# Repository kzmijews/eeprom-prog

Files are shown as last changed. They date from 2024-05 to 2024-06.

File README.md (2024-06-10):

# EEPROM programer

## Overview
EEPROM programer dedicated for AT28C16 memory.
Electrical schema was created in [EAGLE](https://www.autodesk.com/products/eagle/overview):

<div>
    <p align="center" width="100%">
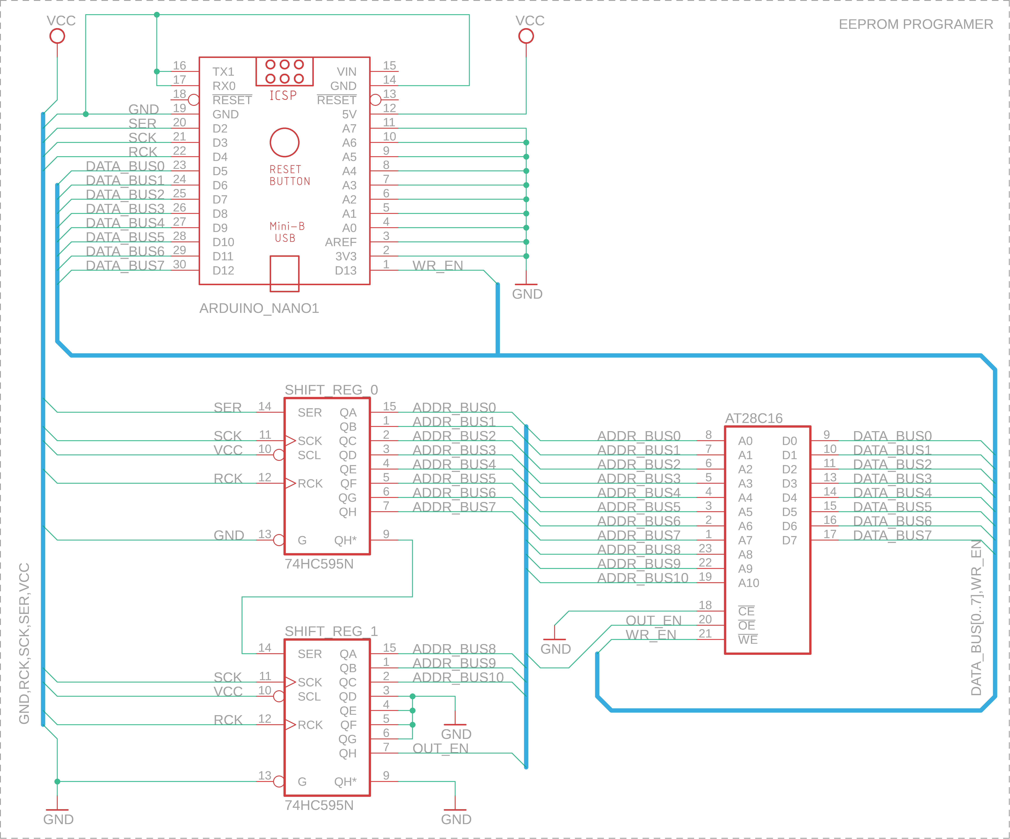
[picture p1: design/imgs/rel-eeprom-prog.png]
        
    </p>
    <p align="center">
        <i>Figure 1.1: EEPROM prog schema</i>
    </p>
</div>

Same as board design:

<div>
    <p align="center" width="100%">
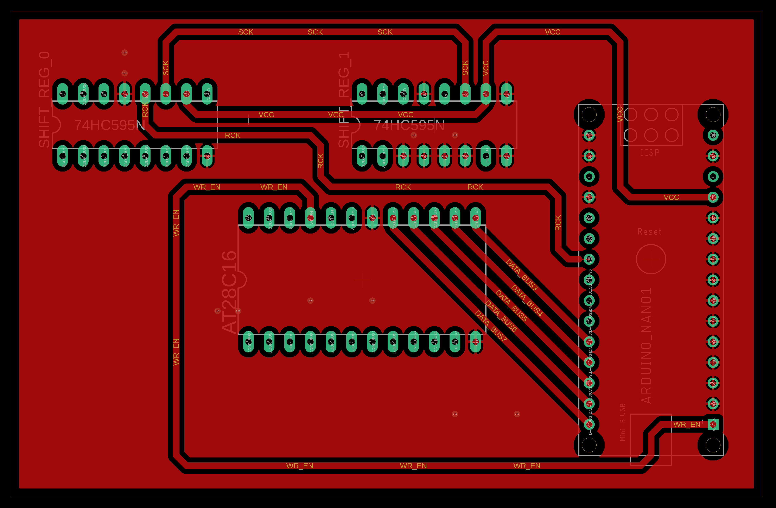
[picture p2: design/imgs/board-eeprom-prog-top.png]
        
    </p>
    <p align="center">
        <i>Figure 1.2: top layer of EEPROM prog board</i>
    </p>
</div>

<div>
    <p align="center" width="100%">
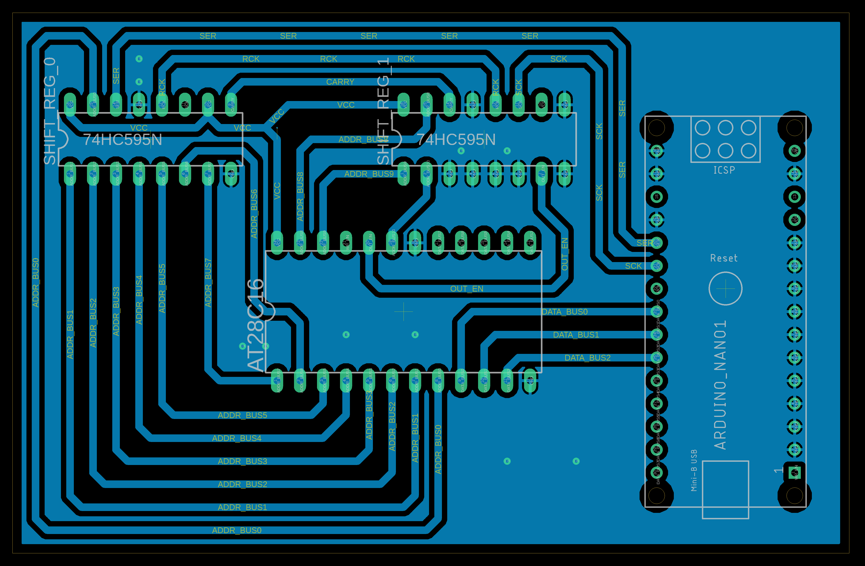
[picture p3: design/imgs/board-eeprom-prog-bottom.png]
        
    </p>
    <p align="center">
        <i>Figure 1.3: bottom layer of EEPROM prog board</i>
    </p>
</div>

It was done based on Arduino Nano 3.0 (ATmega328P):

<div>
    <p align="center" width="100%">
        
    </p>
    <p align="center">
        <i>Figure 1.4: Possible implementation on prototype board</i>
    </p>
</div>

Software library is written in C++, and it's available in `code/eeprom`.
To use it copy `eeprom` folder into your sketch directory (to check directory from [Arduino IDE](https://www.arduino.cc/en/software):
go into: File -> Preferences -> Settings -> Sketchbook location), and load it (Sketch -> Include Library -> eeprom). It will add
"include <eeprom.h>" header file to your project.

## Usage
Available API:
- **begin()**: configure pins and serial output
- **setAddress(unsigned int address, bool rw_bit)**: choose memory address to perform action over the pointed cell
- **read(unsigned int address)**: read byte of data from memory address
- **write(unsigned int address, byte data)**: write byte of data under memory address
- **print(byte data_row_size, unsigned int data_total_size)**: print on serial output (COM) piece of memory content
- **clean()**: write whole memory chip with value 0x00
- **erase()**: erase whole memory chip by writing 0xFF
- **writeAll(byte value)**: write whole memory chip with given value

Example:
```cpp
#include <eeprom.h>

EEPROM eeprom;

void setup() {
    // configure library
    eeprom.begin();
    // write byte (0x01) of data at address 0x00
    eeprom.write(0x00, 0x01);
    // print two rows of data (16 bytes per row, 32 bytes in total)
    eeprom.print(16, 32);
    // read single byte of data from address
    byte read_data = eeprom.read(0x00);
}

void loop() {
}
```

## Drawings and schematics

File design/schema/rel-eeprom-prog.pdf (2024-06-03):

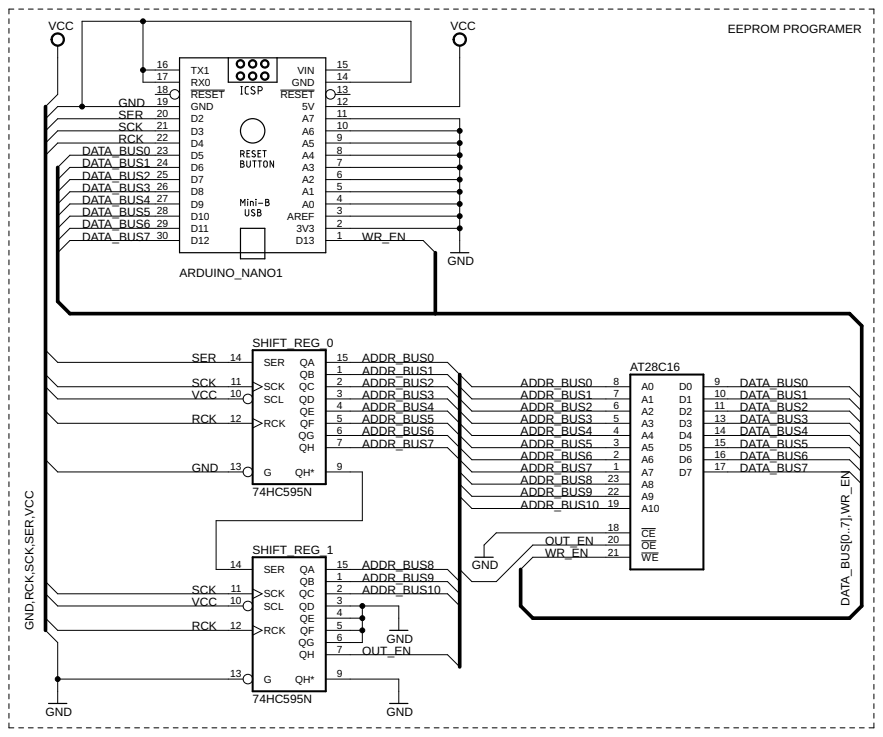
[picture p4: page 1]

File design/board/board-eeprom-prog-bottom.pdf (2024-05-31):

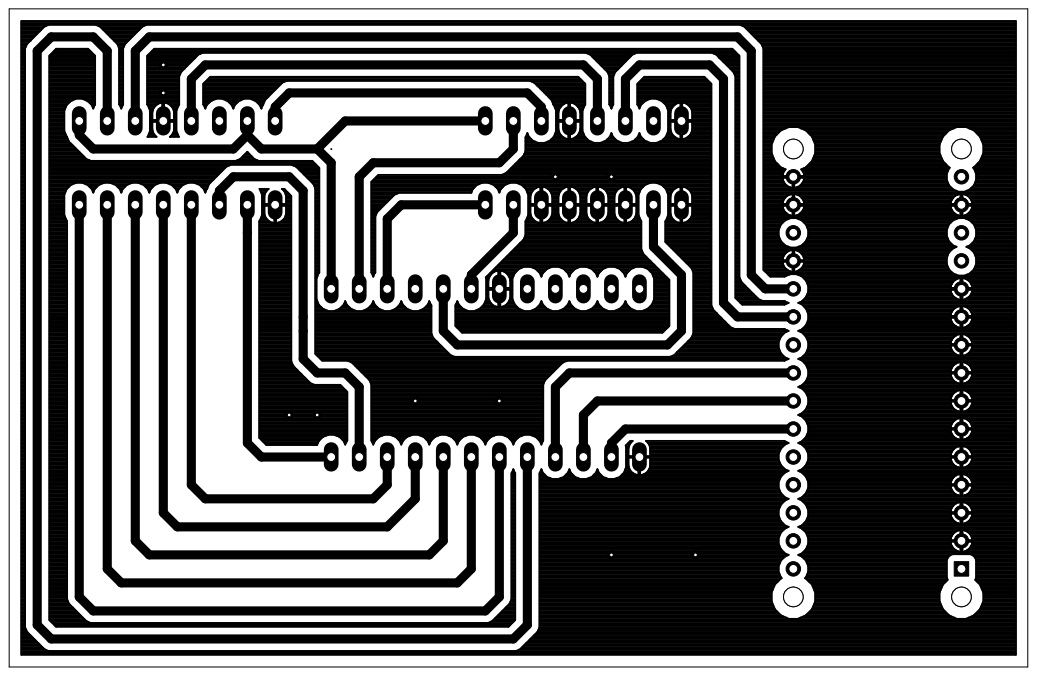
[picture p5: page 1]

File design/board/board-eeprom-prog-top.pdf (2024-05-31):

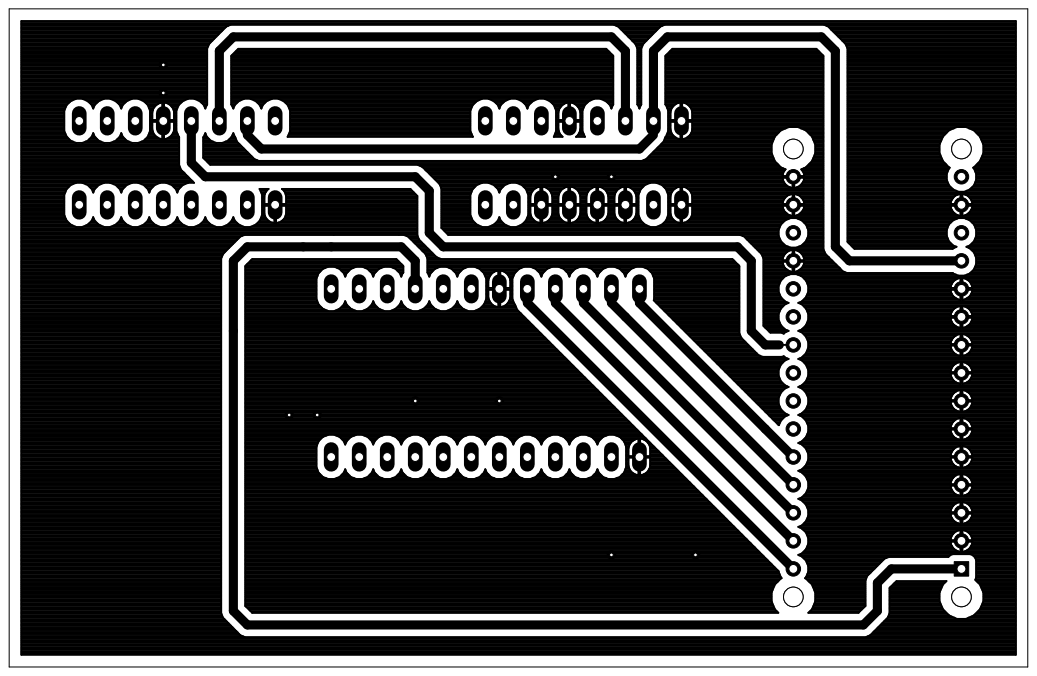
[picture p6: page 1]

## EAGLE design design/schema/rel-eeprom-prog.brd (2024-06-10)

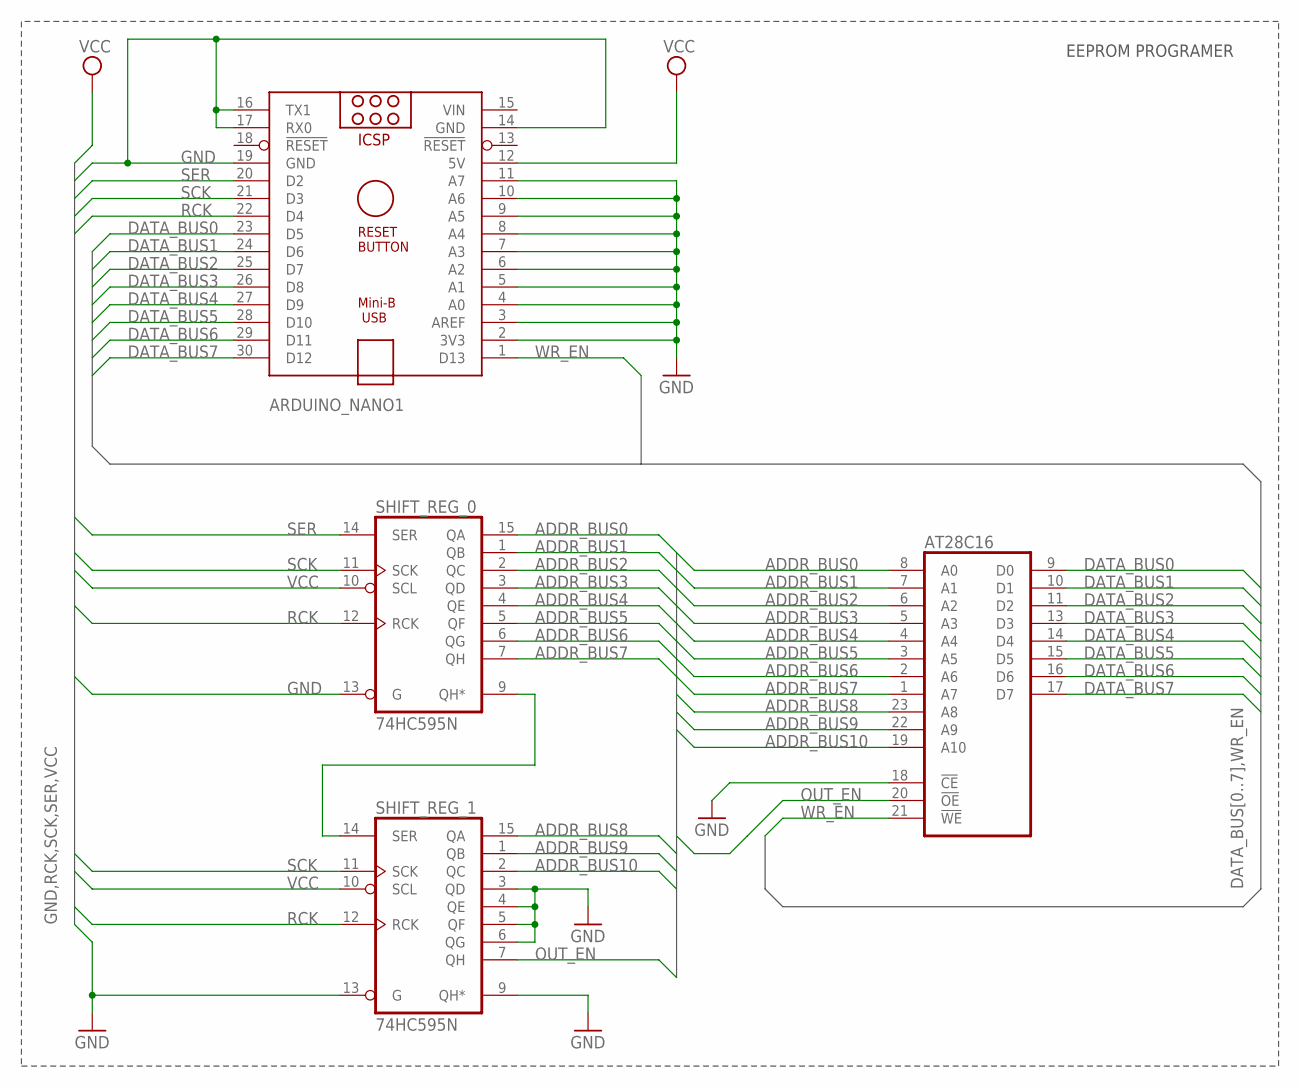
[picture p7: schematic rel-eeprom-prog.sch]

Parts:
ARDUINO_NANO1: ARDUINO_NANO
AT28C16: 2816; DIL24
SHIFT_REG_0, SHIFT_REG_1: 74HC595N; DIL16

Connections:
ADDR_BUS0: AT28C16.8 (A0), SHIFT_REG_0.15 (QA)
ADDR_BUS1: AT28C16.7 (A1), SHIFT_REG_0.1 (QB)
ADDR_BUS2: AT28C16.6 (A2), SHIFT_REG_0.2 (QC)
ADDR_BUS3: AT28C16.5 (A3), SHIFT_REG_0.3 (QD)
ADDR_BUS4: AT28C16.4 (A4), SHIFT_REG_0.4 (QE)
ADDR_BUS5: AT28C16.3 (A5), SHIFT_REG_0.5 (QF)
ADDR_BUS6: AT28C16.2 (A6), SHIFT_REG_0.6 (QG)
ADDR_BUS7: AT28C16.1 (A7), SHIFT_REG_0.7 (QH)
ADDR_BUS8: AT28C16.23 (A8), SHIFT_REG_1.15 (QA)
ADDR_BUS9: AT28C16.22 (A9), SHIFT_REG_1.1 (QB)
ADDR_BUS10: AT28C16.19 (A10), SHIFT_REG_1.2 (QC)
CARRY: SHIFT_REG_0.9 (QH*), SHIFT_REG_1.14 (SER)
DATA_BUS0: ARDUINO_NANO1.23 (D5), AT28C16.9 (D0)
DATA_BUS1: ARDUINO_NANO1.24 (D6), AT28C16.10 (D1)
DATA_BUS2: ARDUINO_NANO1.25 (D7), AT28C16.11 (D2)
DATA_BUS3: ARDUINO_NANO1.26 (D8), AT28C16.13 (D3)
DATA_BUS4: ARDUINO_NANO1.27 (D9), AT28C16.14 (D4)
DATA_BUS5: ARDUINO_NANO1.28 (D10), AT28C16.15 (D5)
DATA_BUS6: ARDUINO_NANO1.29 (D11), AT28C16.16 (D6)
DATA_BUS7: ARDUINO_NANO1.30 (D12), AT28C16.17 (D7)
GND: ARDUINO_NANO1.2 (3V3), ARDUINO_NANO1.3 (AREF), ARDUINO_NANO1.4 (A0), ARDUINO_NANO1.5 (A1), ARDUINO_NANO1.6 (A2), ARDUINO_NANO1.7 (A3), ARDUINO_NANO1.8 (A4), ARDUINO_NANO1.9 (A5), ARDUINO_NANO1.10 (A6), ARDUINO_NANO1.11 (A7), ARDUINO_NANO1.14 (GND), ARDUINO_NANO1.16 (TX1), ARDUINO_NANO1.17 (RX0), ARDUINO_NANO1.19 (GND), AT28C16.12 (GND), AT28C16.18 (!CE), SHIFT_REG_0.8 (GND), SHIFT_REG_0.13 (G), SHIFT_REG_1.3 (QD), SHIFT_REG_1.4 (QE), SHIFT_REG_1.5 (QF), SHIFT_REG_1.6 (QG), SHIFT_REG_1.8 (GND), SHIFT_REG_1.9 (QH*), SHIFT_REG_1.13 (G)
OUT_EN: AT28C16.20 (!OE), SHIFT_REG_1.7 (QH)
RCK: ARDUINO_NANO1.22 (D4), SHIFT_REG_0.12 (RCK), SHIFT_REG_1.12 (RCK)
SCK: ARDUINO_NANO1.21 (D3), SHIFT_REG_0.11 (SCK), SHIFT_REG_1.11 (SCK)
SER: ARDUINO_NANO1.20 (D2), SHIFT_REG_0.14 (SER)
VCC: ARDUINO_NANO1.12 (5V), AT28C16.24 (VCC), SHIFT_REG_0.10 (SCL), SHIFT_REG_0.16 (VCC), SHIFT_REG_1.10 (SCL), SHIFT_REG_1.16 (VCC)
VIN: ARDUINO_NANO1.15 (VIN)
WR_EN: ARDUINO_NANO1.1 (D13), AT28C16.21 (!WE)

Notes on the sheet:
EEPROM PROGRAMER

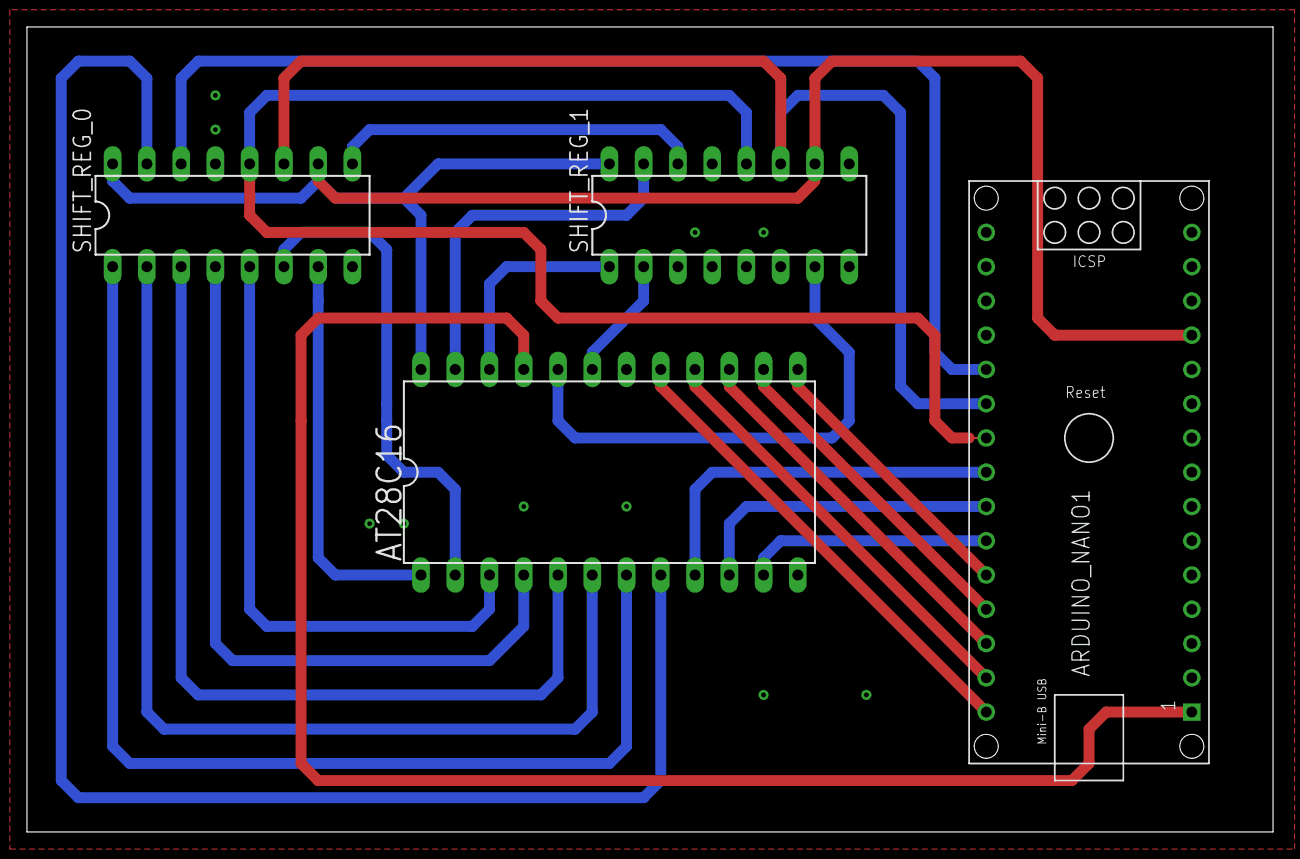
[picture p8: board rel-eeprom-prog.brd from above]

Board: 2 copper layers, 92.4 x 59.7 mm, 4 parts (0 on the bottom side), 27 nets.

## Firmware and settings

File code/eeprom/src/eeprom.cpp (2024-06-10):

/*
    eeprom.cpp - Library for programming EEPROM memory.
    Created by Karol Zmijewski, May 30, 2024.
    Released into the public domain.
*/

#include "Arduino.h"
#include "eeprom.h"
#include<stdio.h>

// ARDUINO PINs layout
#define SER_PIN 2 // DATA SHIFT PIN
#define SCK_PIN 3 // CLK SHIFT PIN
#define RCK_PIN 4 // LATCH SHIFT PIN
#define EEPROM_D0_PIN 5
#define EEPROM_D7_PIN 12
#define WRITE_EN_PIN 13

// EEPROM settings
#define WRITE_EN_MASK 0x80      // 8th pin (0b00000001)
#define WRITE_OP_TIME_MS 5      // time needed to fnish write operation in miliseconds
#define WRITE_SIG_DURATION_NS 1 // write signal duration time in nanoseconds, depends on EEPROM spec
#define EEPROM_SIZE 2048        // 2KB EEPROM memory
#define SERIAL_OUT_FREQ 57600


EEPROM::EEPROM() {
}

void EEPROM::begin() {
    Serial.begin(SERIAL_OUT_FREQ);
    pinMode(SER_PIN, OUTPUT);
    pinMode(SCK_PIN, OUTPUT);
    pinMode(RCK_PIN, OUTPUT);
    digitalWrite(WRITE_EN_PIN, HIGH); // prevent from acidental write to the EEPROM
    pinMode(WRITE_EN_PIN, OUTPUT);
}

void EEPROM::setAddress(unsigned int address, bool rw_bit) {
    shiftOut(SER_PIN, SCK_PIN, MSBFIRST, (address >> 8) | (rw_bit ? 0x00 : WRITE_EN_MASK));
    shiftOut(SER_PIN, SCK_PIN, MSBFIRST, address);
    // toggle the pin - make sure that clock pin is at low state before rasing it,
    // regarding to doc, action will be triggeredon rising edge of the signal
    digitalWrite(RCK_PIN , LOW);
    digitalWrite(RCK_PIN , HIGH);
    digitalWrite(RCK_PIN , LOW);
}

byte EEPROM::read(unsigned int address) {
    for(int pin_id = EEPROM_D0_PIN; pin_id <= EEPROM_D7_PIN; pin_id++) {
        // Arduino input, EEPROM output
        pinMode(pin_id, INPUT);
    }
    setAddress(address, true);
    byte data = 0xFF;
    for(int pin_id = EEPROM_D7_PIN; pin_id >= EEPROM_D0_PIN; pin_id--) {
        data = (data << 1) + digitalRead(pin_id);
    }
    return data;
}

void EEPROM::write(unsigned int address, byte data) {
    for(int pin_id = EEPROM_D0_PIN; pin_id <= EEPROM_D7_PIN; pin_id++) {
        // Arduino output, EEPROM input
        pinMode(pin_id, OUTPUT);
    }
    setAddress(address, false);
    for(int pin_id = EEPROM_D0_PIN; pin_id <= EEPROM_D7_PIN; pin_id++) {
        digitalWrite(pin_id, data & 1);
        data = data >> 1;
    }
    digitalWrite(WRITE_EN_PIN, LOW);
    delayMicroseconds(WRITE_SIG_DURATION_NS);
    digitalWrite(WRITE_EN_PIN, HIGH);
    delay(WRITE_OP_TIME_MS);
}

void EEPROM::print(byte data_row_size, unsigned int data_total_size) {
    Serial.println("\n");
    if(data_total_size > EEPROM_SIZE) {
        char* err_msg = (char*) malloc(122);
        sprintf(err_msg, "Cannot read %u bytes from EEPROM, because the max size of memory is equal to %u. Whole memory will be read:\0", data_total_size, EEPROM_SIZE);
        Serial.println(err_msg);
        free(err_msg);
        data_total_size = EEPROM_SIZE;
    }
    const byte BASE_ADDR_CHARS_SIZE = 2 * sizeof(unsigned int);        // two characters needed to represent one byte
    const byte ADDITIONAL_CHARS_SIZE = 2 * sizeof(char);               // additional characters: ':' and '\0' (end of string)
    const byte DATA_ROW_CHARS_SIZE = 2 * data_row_size * sizeof(char); // two characters needed to represent each byte of data in row
    const byte WHITE_CHARS_SIZE = data_row_size * sizeof(char);        // additional white character after each byte of data
    const byte TOTAL_ROW_SIZE = BASE_ADDR_CHARS_SIZE + ADDITIONAL_CHARS_SIZE + DATA_ROW_CHARS_SIZE + WHITE_CHARS_SIZE + TOTAL_ROW_SIZE;
    // fulfill row string of data
    char* p_serial_out_buf = (char*) malloc(TOTAL_ROW_SIZE);
    for(unsigned int base_addr = 0x00; base_addr < data_total_size; base_addr += data_row_size) {
        int serial_out_buf_offset = sprintf(p_serial_out_buf, "%08x: ", base_addr);
        for(unsigned int offset_addr = 0; offset_addr < data_row_size; offset_addr++) {
            serial_out_buf_offset += sprintf(p_serial_out_buf + serial_out_buf_offset, "%02x ", read(base_addr + offset_addr));
        }
        p_serial_out_buf[serial_out_buf_offset] = '\0';
        Serial.println(p_serial_out_buf);
    }
    free(p_serial_out_buf);
    Serial.println("\n");
}

void EEPROM::writeAll(byte value) {
    for(unsigned int address = 0x0; address < EEPROM_SIZE; address++) {
        byte curr_byte_val = read(address);
        if(curr_byte_val != value) {
            write(address, value);
        }
    }
}

void EEPROM::clean() {
    const byte EMPTY_BYTE = 0x00;
    writeAll(EMPTY_BYTE);
}

void EEPROM::erase() {
    const byte ERASED_BYTE = 0xFF;
    writeAll(ERASED_BYTE);
}

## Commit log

2024-05-30 Added initial version of EEPROM programer
    [rel-eeprom-prog.sch]
2024-05-30 Fixed for improper pull down on SCL pin
    [rel-eeprom-prog.sch]
2024-05-30 Fixed serial output configuration
    [eeprom.cpp]
2024-05-31 Added initial version of board design
    [rel-eeprom-prog.brd, rel-eeprom-prog.sch]
2024-06-03 Updated IC chips names
    [rel-eeprom-prog.brd, rel-eeprom-prog.sch]
2024-06-10 Added erase and writeAll API methods
    [rel-eeprom-prog.brd, rel-eeprom-prog.sch]
